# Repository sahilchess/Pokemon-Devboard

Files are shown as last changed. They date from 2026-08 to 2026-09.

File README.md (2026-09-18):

# [Pokemon Devboard](https://kicanvas.org/?repo=https%3A%2F%2Fgithub.com%2Fsahilchess%2FPokemon-Devboard%2Ftree%2Fmain%2FPCB_DESIGN)
 
a pokemon themed rp2040 dev board designed in kicad, arduino lookalike

[woah whats this?](https://forge.hackclub.com/projects/1680)



## features
 
- rp2040 mcu, 30 gpio broken out
- usb_c input with mcp1700 3.3v regulator
- w25q128jvs 16mb qspi flash for program storage
- 12mhz crystal oscillator
- reset button and bootsel button
- 2 user leds on gpio2 and gpio3
- 2 user buttons on gpio4 and gpio5
- swd debug header (swclk, swdio, gnd)
- gpioa and gpiob headers for full pin access
- power headers for gnd, 3v3, and 5v lines
- test pads for gnd, 3v3, 5v, swclk, swdio, run, and 2 mounting holes
- clear pinouts with silkscreen

## why i made this

i've always liked the arduino form factor. it's simple and just works. everyone knows it. but here's what got me thinkin, arduino is literally the biggest mcu maker in the world and they never made the chip better. they just stuck with the old 8-bit avrs while everything else moved on to faster processors.

so i wondered, what if i could take the rp2040, which is actually good, and put it in that arduino shape? no one was doing it. so i did it.

making this taught me a ton about power delivery, flash wiring, schematic design, all the stuff that goes into actually making something people can use. and honestly, it's just cool to know i bridged that gap. the arduino form factor is iconic because it works, and the rp2040 is fast and has tons of gpio. now you get both.

if you build with this, you get the form factor you already know how to use but way more power under the hood.

## power
 
usb_c feeds vbus into the mcp1700 330xxtt regulator, output is 3.3v and 5v. decoupling caps sit across usb_vdd, adc_avdd, vreg_vin, vreg_vout, and dvdd per the rp2040 datasheet recommendations.
 
## flash
 
w25q128jvs wired to the rp2040 qspi bus (qspi_ss, qspi_sclk, qspi_sd0 to sd3). sw1 is the bootsel button, pulls qspi_ss to select flash bootrom mode on boot.
 
## files
 
- pcb_design, kicad project, schematic and board layout
- production, gerbers and fab outputs ready to send out
- gerber.zip, zipped gerbers for ordering
- readme.md, this file

## getting started

just plug it in.

plug usb_c into your computer. it should show up as a usb device. download the rp2040 sdk or use the arduino ide with the rp2040 board package installed.

if you want to load firmware, hit the bootsel button (sw1) while plugging in usb or while pressing reset. this puts the board into bootloader mode and a new drive shows up on your computer. drag your .uf2 file onto it and you're done.

if you want to use the swd header for debugging, you need a debugger (picoprobe, j-link, whatever you have). the header is swclk, swdio, and gnd. connect them and you can step through code with gdb.

the two leds on gpio2 and gpio3 blink by default on boot so you know it's working. the two buttons on gpio4 and gpio5 are yours to do whatever with.

all 30 gpio pins are on the gpioa and gpiob headers so you can break out whatever you need. power headers have gnd, 3v3, and 5v if you're powering other stuff.

firmware: simple blink.ino [here](https://github.com/sahilchess/Pokemon-Devboard/blob/main/production/blink.ino)

## status
 
ready to buy from jlcpcb,prolly wont tho and will just redeem coins from shop.

## pictures






## Bill of Materials
[here](https://github.com/sahilchess/Pokemon-Devboard/blob/main/production/bom.csv)
<!--
| Component | Value | Qty | Footprint | LCSC Part # | Link | Unit Cost | Total |
|---|---|-----|---|---|---|---|---|
| C1-C8, C11, C12, C17 | 0.1µF | 11 | 0402 | C1525 | [LCSC](https://www.lcsc.com/product-detail/C1525.html?s_z=n_q_C1525&globalKeyword=C1525) | $0.0055 | $0.0605 |
| C9, C10 | 1µF | 2 | 0402 | C52923 | [LCSC](https://www.lcsc.com/product-detail/C52923.html?s_z=n_q_C52923&globalKeyword=C52923) | $0.0126 | $0.0252 |
| C13, C14 | 10µF | 2 | 0603 | C19702 | [LCSC](https://www.lcsc.com/product-detail/C19702.html?s_z=n_q_C19702&globalKeyword=C19702) | $0.0391 | $0.0782 |
| C15, C16 | 33pF | 2 | 0402 | C1562 | [LCSC](https://www.lcsc.com/product-detail/C1562.html?s_z=n_q_C1562&globalKeyword=C1562) | $0.0072 | $0.0144 |
| GPIO2, GPIO3 | LED | 2 | 0805 | C2297 | [LCSC](https://www.lcsc.com/product-detail/C2297.html?s_z=n_q_C2297&globalKeyword=C2297) | $0.0163 | $0.0326 |
| GPIO4, GPIO5, RUN1, SW1 | SW_Push | 4 | Alps SKRK | C720477 | [LCSC](https://www.lcsc.com/product-detail/C720477.html?s_z=n_q_C720477&globalKeyword=C720477) | $0.0531 | $0.2124 |
| J1 | USB-C Receptacle | 1 | HRO TYPE-C-31-M-12 | C165948 | [LCSC](https://www.lcsc.com/product-detail/C165948.html?s_z=n_q_C165948&globalKeyword=C165948) | $0.1716 | $0.1716 |
| J2 | GPIO Bank B | 1 | 1x11 Pin Socket | C124407 | [LCSC](https://www.lcsc.com/product-detail/C124407.html?s_z=n_q_C124407&globalKeyword=C124407) | $0.2734 | $0.2734 |
| J4 | GPIO Bank A | 1 | 1x18 Pin Socket | C124410 | [LCSC](https://www.lcsc.com/product-detail/C124410.html?s_z=n_q_C124410&globalKeyword=C124410) | $0.367 | $0.367 |
| J5 | Debug | 1 | 1x3 Pin Socket | C49257 | [LCSC](https://www.lcsc.com/product-detail/C49257.html?s_z=n_q_C49257&globalKeyword=C49257) | $0.0272 | $0.0272 |
| J6 | Power | 1 | 1x5 Pin Socket | C124414 | [LCSC](https://www.lcsc.com/product-detail/C124414.html?s_z=n_q_C124414&globalKeyword=C124414) | $0.1323 | $0.1323 |
| J8 | GND Line | 1 | 1x10 Pin Socket | C124407 | [LCSC](https://www.lcsc.com/product-detail/C124407.html?s_z=n_q_C124407&globalKeyword=C124407) | $0.2734 | $0.2734 |
| J9 | 3V3 Line | 1 | 1x10 Pin Socket | C124407 | [LCSC](https://www.lcsc.com/product-detail/C124407.html?s_z=n_q_C124407&globalKeyword=C124407) | $0.2734 | $0.2734 |
| J11 | 5V Line | 1 | 1x10 Pin Socket | C124407 | [LCSC](https://www.lcsc.com/product-detail/C124407.html?s_z=n_q_C124407&globalKeyword=C124407) | $0.2734 | $0.2734 |
| R1, R2 | 5.1K | 2 | 0402 | C25905 | [LCSC](https://www.lcsc.com/product-detail/C25905.html?s_z=n_q_C25905&globalKeyword=C25905) | $0.0043 | $0.0086 |
| R9, R10 | 220Ω | 2 | 0402 | C25091 | [LCSC](https://www.lcsc.com/product-detail/C25091.html?s_z=n_q_C25091&globalKeyword=C25091) | $0.0062 | $0.0124 |
| R3, R4 | 22Ω | 2 | 0402 | C25092 | [LCSC](https://www.lcsc.com/product-detail/C25092.html?s_z=n_q_C25092&globalKeyword=C25092) | $0.007 | $0.014 |
| R5, R7 | 1K | 2 | 0402 | C11702 | [LCSC](https://www.lcsc.com/product-detail/C11702.html?s_z=n_q_C11702&globalKeyword=C11702) | $0.0067 | $0.0134 |
| R6, R8, R11 | 10K | 3 | 0805 | C17414 | [LCSC](https://www.lcsc.com/product-detail/C17414.html?s_z=n_q_C17414&globalKeyword=C17414) | $0.0056 | $0.0168 |
| U1 | RP2040 | 1 | QFN-56 | C2040 | [LCSC](https://www.lcsc.com/product-detail/C2040.html?s_z=n_q_C2040&globalKeyword=C2040) | $0.993 | $0.993 |
| U2 | MCP1700x-330 | 1 | SOT-23 | C5446 | [LCSC](https://www.lcsc.com/product-detail/C5446.html?s_z=n_q_C5446&globalKeyword=C5446) | $0.1362 | $0.1362 |
| U3 | W25Q128JVS | 1 | SOIC-8 | C97521 | [LCSC](https://www.lcsc.com/product-detail/C97521.html?s_z=n_q_C97521&globalKeyword=C97521) | $2.5773 | $2.5773 |
| Y2 | 12MHz Crystal | 1 | 3225 4-Pin | C9002 | [LCSC](https://www.lcsc.com/product-detail/C9002.html?s_z=n_q_C9002&globalKeyword=C9002) | $0.0953 | $0.0953 |

**Total Components:** 72  
**Estimated Build Cost:** $48.28 USD

-->

**made for forge**

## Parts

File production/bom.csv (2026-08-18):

Component | Value | Quantity | Footprint | LCSC Part # | Link | Unit Cost (USD) | Total Cost (USD)
C1-C8, C11, C12, C17 | 0.1µF | 11 | 0402 | C1525 | https://www.lcsc.com/product-detail/C1525.html?s_z=n_q_C1525&globalKeyword=C1525 | 0.0055 | 0.0605
C9, C10 | 1µF | 2 | 0402 | C52923 | https://www.lcsc.com/product-detail/C52923.html?s_z=n_q_C52923&globalKeyword=C52923 | 0.0126 | 0.0252
C13, C14 | 10µF | 2 | 0603 | C19702 | https://www.lcsc.com/product-detail/C19702.html?s_z=n_q_C19702&globalKeyword=C19702 | 0.0391 | 0.0782
C15, C16 | 33pF | 2 | 0402 | C1562 | https://www.lcsc.com/product-detail/C1562.html?s_z=n_q_C1562&globalKeyword=C1562 | 0.0072 | 0.0144
GPIO2, GPIO3 | LED | 2 | 0805 | C2297 | https://www.lcsc.com/product-detail/C2297.html?s_z=n_q_C2297&globalKeyword=C2297 | 0.0163 | 0.0326
GPIO4, GPIO5, RUN1, SW1 | SW_Push | 4 | Alps SKRK | C720477 | https://www.lcsc.com/product-detail/C720477.html?s_z=n_q_C720477&globalKeyword=C720477 | 0.0531 | 0.2124
J1 | USB-C Receptacle | 1 | HRO TYPE-C-31-M-12 | C165948 | https://www.lcsc.com/product-detail/C165948.html?s_z=n_q_C165948&globalKeyword=C165948 | 0.1716 | 0.1716
J2 | GPIO Bank B | 1 | 1x11 Pin Socket | C124407 | https://www.lcsc.com/product-detail/C124407.html?s_z=n_q_C124407&globalKeyword=C124407 | 0.2734 | 0.2734
J4 | GPIO Bank A | 1 | 1x18 Pin Socket | C124410 | https://www.lcsc.com/product-detail/C124410.html?s_z=n_q_C124410&globalKeyword=C124410 | 0.367 | 0.367
J5 | Debug | 1 | 1x3 Pin Socket | C49257 | https://www.lcsc.com/product-detail/C49257.html?s_z=n_q_C49257&globalKeyword=C49257 | 0.0272 | 0.0272
J6 | Power | 1 | 1x5 Pin Socket | C124414 | https://www.lcsc.com/product-detail/C124414.html?s_z=n_q_C124414&globalKeyword=C124414 | 0.1323 | 0.1323
J8 | GND Line | 1 | 1x10 Pin Socket | C124407 | https://www.lcsc.com/product-detail/C124407.html?s_z=n_q_C124407&globalKeyword=C124407 | 0.2734 | 0.2734
J9 | 3V3 Line | 1 | 1x10 Pin Socket | C124407 | https://www.lcsc.com/product-detail/C124407.html?s_z=n_q_C124407&globalKeyword=C124407 | 0.2734 | 0.2734
J11 | 5V Line | 1 | 1x10 Pin Socket | C124407 | https://www.lcsc.com/product-detail/C124407.html?s_z=n_q_C124407&globalKeyword=C124407 | 0.2734 | 0.2734
R1, R2 | 5.1K | 2 | 0402 | C25905 | https://www.lcsc.com/product-detail/C25905.html?s_z=n_q_C25905&globalKeyword=C25905 | 0.0043 | 0.0086
R9, R10 | 220Ω | 2 | 0402 | C25091 | https://www.lcsc.com/product-detail/C25091.html?s_z=n_q_C25091&globalKeyword=C25091 | 0.0062 | 0.0124
R3, R4 | 22Ω | 2 | 0402 | C25092 | https://www.lcsc.com/product-detail/C25092.html?s_z=n_q_C25092&globalKeyword=C25092 | 0.007 | 0.014
R5, R7 | 1K | 2 | 0402 | C11702 | https://www.lcsc.com/product-detail/C11702.html?s_z=n_q_C11702&globalKeyword=C11702 | 0.0067 | 0.0134
R6, R8, R11 | 10K | 3 | 0805 | C17414 | https://www.lcsc.com/product-detail/C17414.html?s_z=n_q_C17414&globalKeyword=C17414 | 0.0056 | 0.0168
U1 | RP2040 | 1 | QFN-56 | C2040 | https://www.lcsc.com/product-detail/C2040.html?s_z=n_q_C2040&globalKeyword=C2040 | 0.993 | 0.993
U2 | MCP1700x-330 | 1 | SOT-23 | C5446 | https://www.lcsc.com/product-detail/C5446.html?s_z=n_q_C5446&globalKeyword=C5446 | 0.1362 | 0.1362
U3 | W25Q128JVS | 1 | SOIC-8 | C97521 | https://www.lcsc.com/product-detail/C97521.html?s_z=n_q_C97521&globalKeyword=C97521 | 2.5773 | 2.5773
Y2 | 12MHz Crystal | 1 | 3225 4-Pin | C9002 | https://www.lcsc.com/product-detail/C9002.html?s_z=n_q_C9002&globalKeyword=C9002 | 0.0953 | 0.0953

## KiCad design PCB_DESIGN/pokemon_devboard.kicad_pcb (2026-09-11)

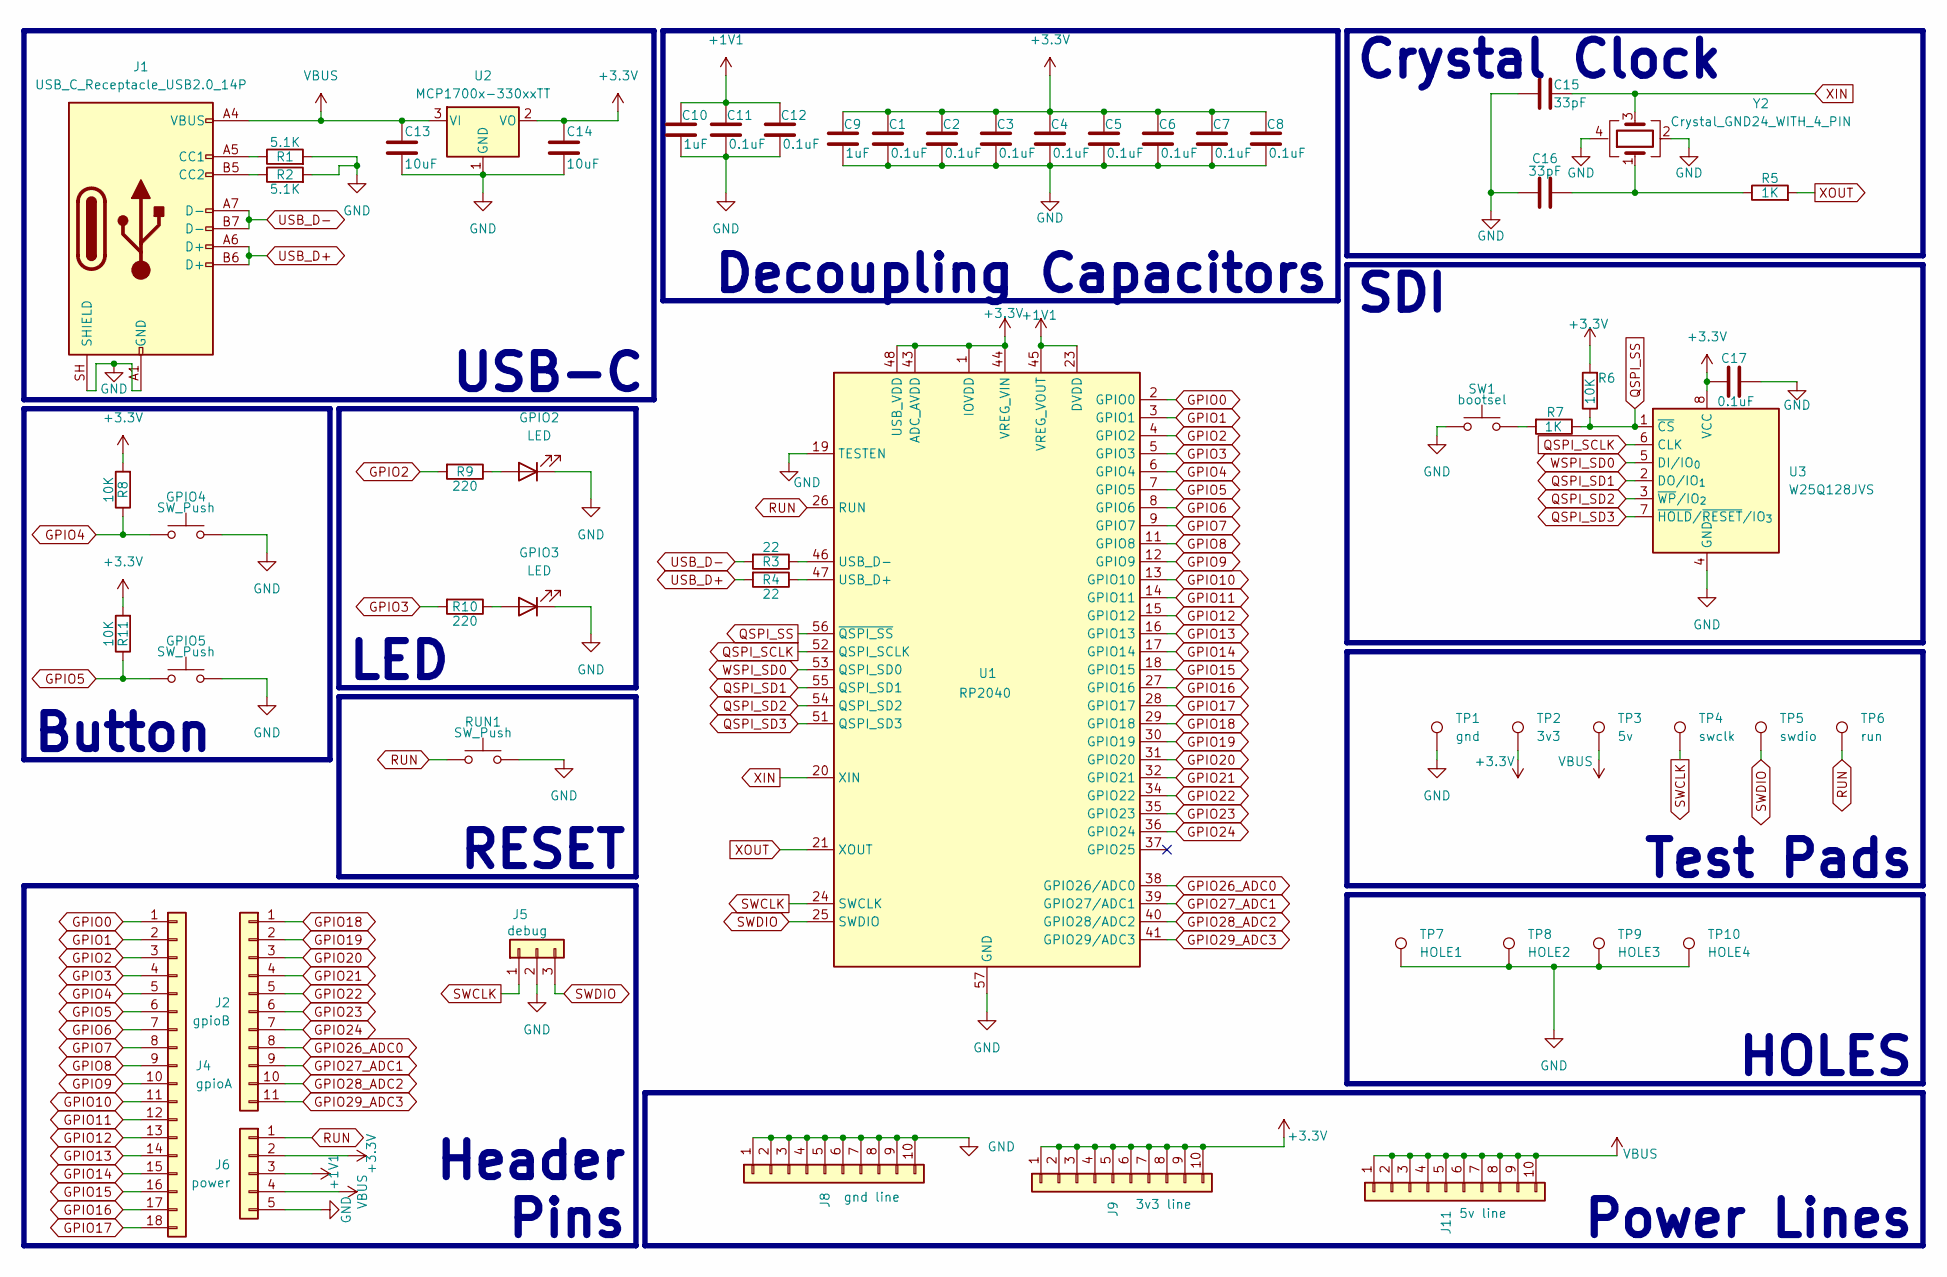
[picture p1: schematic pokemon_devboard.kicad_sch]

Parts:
C1, C2, C3, C4, C5, C6, C7, C8, C11, C12, C17: 0.1uF; C_0402_1005Metric
C9, C10: 1uF; C_0402_1005Metric
C13, C14: 10uF; C_0603_1608Metric
C15, C16: 33pF; C_0402_1005Metric
GPIO2, GPIO3: LED; LED_0805_2012Metric
GPIO4, GPIO5: SW_Push; SW_Push_SPST_NO_Alps_SKRK
J1: USB_C_Receptacle_USB2.0_14P; USB_C_Receptacle_HRO_TYPE-C-31-M-12
J2: gpioB; PinSocket_1x11_P2.54mm_Vertical
J4: gpioA; PinSocket_1x18_P2.54mm_Vertical
J5: debug; PinSocket_1x03_P2.54mm_Vertical
J6: power; PinSocket_1x05_P2.54mm_Vertical
J8: gnd line; PinSocket_1x10_P2.54mm_Vertical
J9: 3v3 line; PinSocket_1x10_P2.54mm_Vertical
J11: 5v line; PinSocket_1x10_P2.54mm_Vertical
R1, R2: 5.1K; R_0402_1005Metric
R3, R4: 22; R_0402_1005Metric
R5, R7: 1K; R_0402_1005Metric
R6, R8, R11: 10K; R_0805_2012Metric
R9, R10: 220; R_0402_1005Metric
RUN1: SW_Push; SW_Push_SPST_NO_Alps_SKRK
SW1: bootsel; SW_Push_SPST_NO_Alps_SKRK
TP1: gnd; TestPoint_Pad_D1.5mm
TP2: 3v3; TestPoint_Pad_D1.5mm
TP3: 5v; TestPoint_Pad_D1.5mm
TP4: swclk; TestPoint_Pad_D1.5mm
TP5: swdio; TestPoint_Pad_D1.5mm
TP6: run; TestPoint_Pad_D1.5mm
TP7: HOLE1; MountingHole_2.2mm_M2_Pad
TP8: HOLE2; MountingHole_2.2mm_M2_Pad
TP9: HOLE3; MountingHole_2.2mm_M2_Pad
TP10: HOLE4; MountingHole_2.2mm_M2_Pad
U1: RP2040; QFN-56-1EP_7x7mm_P0.4mm_EP3.2x3.2mm
U2: MCP1700x-330xxTT; SOT-23
U3: W25Q128JVS; SOIC-8_5.3x5.3mm_P1.27mm
Y2: Crystal_GND24_WITH_4_PIN; Crystal_SMD_3225-4Pin_3.2x2.5mm

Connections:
+1V1: C10.1, C11.1, C12.1, J6.3, U1.23 (DVDD), U1.45 (VREG_VOUT), U1.50 (DVDD)
+3.3V: C1.1, C2.1, C3.1, C4.1, C5.1, C6.1, C7.1, C8.1, C9.1, C14.1, C17.1, J6.2, J9.1, J9.2, J9.3, J9.4, J9.5, J9.6, J9.7, J9.8, J9.9, J9.10, R6.2, R8.2, R11.2, TP2.1 (1_1), U1.1 (IOVDD), U1.10 (IOVDD), U1.22 (IOVDD), U1.33 (IOVDD), U1.42 (IOVDD), U1.43 (ADC_AVDD), U1.44 (VREG_VIN), U1.48 (USB_VDD), U1.49 (IOVDD), U2.2 (VO), U3.8 (VCC)
GND: C1.2, C2.2, C3.2, C4.2, C5.2, C6.2, C7.2, C8.2, C9.2, C10.2, C11.2, C12.2, C13.2, C14.2, C15.1, C16.1, C17.2, GPIO2.1 (K), GPIO3.1 (K), GPIO4.2, GPIO5.2, J1.A1 (GND), J1.A12 (GND), J1.B1 (GND), J1.B12 (GND), J1.SH (SHIELD), J5.2, J6.5, J8.1, J8.2, J8.3, J8.4, J8.5, J8.6, J8.7, J8.8, J8.9, J8.10, R1.2, R2.2, RUN1.2, SW1.1, TP1.1 (1_1), TP7.1 (1_1), TP8.1 (1_1), TP9.1 (1_1), TP10.1 (1_1), U1.19 (TESTEN), U1.57 (GND), U2.1 (GND), U3.4 (GND), Y2.2 (G), Y2.4
GPIO0: J4.1, U1.2 (GPIO0)
GPIO1: J4.2, U1.3 (GPIO1)
GPIO2: J4.3, R9.2, U1.4 (GPIO2)
GPIO3: J4.4, R10.2, U1.5 (GPIO3)
GPIO4: GPIO4.1, J4.5, R8.1, U1.6 (GPIO4)
GPIO5: GPIO5.1, J4.6, R11.1, U1.7 (GPIO5)
GPIO6: J4.7, U1.8 (GPIO6)
GPIO7: J4.8, U1.9 (GPIO7)
GPIO8: J4.9, U1.11 (GPIO8)
GPIO9: J4.10, U1.12 (GPIO9)
GPIO10: J4.11, U1.13 (GPIO10)
GPIO11: J4.12, U1.14 (GPIO11)
GPIO12: J4.13, U1.15 (GPIO12)
GPIO13: J4.14, U1.16 (GPIO13)
GPIO14: J4.15, U1.17 (GPIO14)
GPIO15: J4.16, U1.18 (GPIO15)
GPIO16: J4.17, U1.27 (GPIO16)
GPIO17: J4.18, U1.28 (GPIO17)
GPIO18: J2.1, U1.29 (GPIO18)
GPIO19: J2.2, U1.30 (GPIO19)
GPIO20: J2.3, U1.31 (GPIO20)
GPIO21: J2.4, U1.32 (GPIO21)
GPIO22: J2.5, U1.34 (GPIO22)
GPIO23: J2.6, U1.35 (GPIO23)
GPIO24: J2.7, U1.36 (GPIO24)
GPIO26_ADC0: J2.8, U1.38 (GPIO26/ADC0)
GPIO27_ADC1: J2.9, U1.39 (GPIO27/ADC1)
GPIO28_ADC2: J2.10, U1.40 (GPIO28/ADC2)
GPIO29_ADC3: J2.11, U1.41 (GPIO29/ADC3)
unnamed: C16.2, R5.1, Y2.1
unnamed: GPIO2.2 (A), R9.1
unnamed: GPIO3.2 (A), R10.1
unnamed: J1.A5 (CC1), R1.1
unnamed: J1.B5 (CC2), R2.1
unnamed: R7.2, SW1.2
unnamed: R4.1, U1.47 (USB_D+)
unnamed: R3.1, U1.46 (USB_D-)
QSPI_SCLK: U1.52 (QSPI_SCLK), U3.6 (CLK)
QSPI_SD1: U1.55 (QSPI_SD1), U3.2 (DO/IO_{1})
QSPI_SD2: U1.54 (QSPI_SD2), U3.3 (~WP/IO_{2})
QSPI_SD3: U1.51 (QSPI_SD3), U3.7 (~HOLD/~RESET/IO_{3})
QSPI_SS: R6.1, R7.1, U1.56 (~QSPI_SS), U3.1 (~CS)
RUN: J6.1, RUN1.1, TP6.1 (1_1), U1.26 (RUN)
SWCLK: J5.1, TP4.1 (1_1), U1.24 (SWCLK)
SWDIO: J5.3, TP5.1 (1_1), U1.25 (SWDIO)
USB_D+: J1.A6 (D+), J1.B6 (D+), R4.2
USB_D-: J1.A7 (D-), J1.B7 (D-), R3.2
VBUS: C13.1, J1.A4 (VBUS), J1.A9 (VBUS), J1.B4 (VBUS), J1.B9 (VBUS), J6.4, J11.1, J11.2, J11.3, J11.4, J11.5, J11.6, J11.7, J11.8, J11.9, J11.10, TP3.1 (1_1), U2.3 (VI)
WSPI_SD0: U1.53 (QSPI_SD0), U3.5 (DI/IO_{0})
XIN: C15.2, U1.20 (XIN), Y2.3
XOUT: R5.2, U1.21 (XOUT)

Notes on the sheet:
SDI
USB-C
Decoupling Capacitors
HOLES
Test Pads
LED
Button
Power Lines
RESET
Crystal Clock
Header Pins

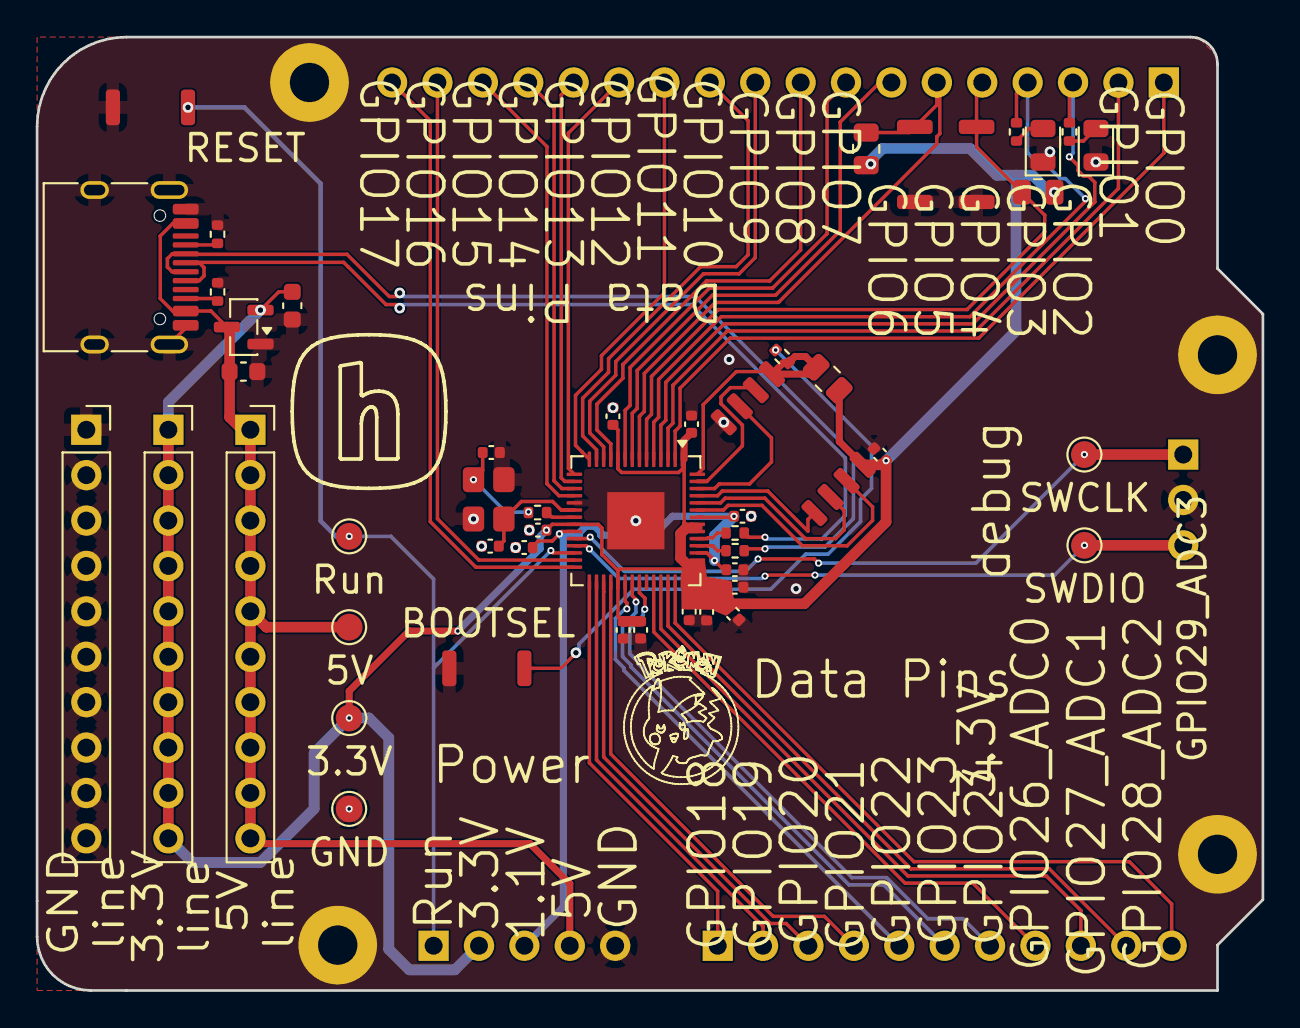
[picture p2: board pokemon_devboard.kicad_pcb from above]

Board: 2 copper layers, 68.6 x 53.3 mm, 56 parts (0 on the bottom side), 54 nets.

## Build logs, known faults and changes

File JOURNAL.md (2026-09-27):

---
title: "Pokemon Devboard"
author: "sahil"
description: "RP2040 development board inspired by Arduino shape with Pokémon theming"
created_at: "2026-05-25"
---

# May 25: the idea

For the idea, I wanted to create a custom devboard because I thought that was cool. I didn't know how to so I will follow a guide on Macondo. Imma choose a Pokémon theme because i love Pokémon (obviously).  



**Total time spent: 0 hours**

# May 25: Started the schematic

after a meeting with a macondo guide, i read the room and saw that most of it was: see raspberry pi pico, find that part datasheet, put it in schematic. so imma leave the guide and do it myself... here is the RP2040 with the decoupling caps. these are needed to stabilize voltage and reduce high-frequency noise



hackatime: [14m](https://lapse.hackclub.com/timelapse/PWaohIea3p6Q) -- [1hr 20m](https://lapse.hackclub.com/timelapse/IpuH7RUJf16H)

**Total time spent: 1.6 hours**

# May 25: working on schematic

firstly, the usb is needed to get power to the stuff. next, we have the buttons and leds that are meta with custom devboards. and lastly, we have our crystal and SDI for flash memory and the crystal for a clock. I had to go to the websites to find the datasheets. i was easily able to find these after searching up the par





i realized I also need header pins so here they are. Additionally, I added those cool blue boxes for labeling the parts and stuff. here is the finished design





hackatime: [1hr 12m](https://lapse.hackclub.com/timelapse/twbUsFzCFTM-) 
i will put 1 hr cuz i lolled around a bit.

**Total time spent: 1.2 hours**

# May 26: placed parts!

now that i finished assigning parts, i also finished placing all my parts on the board. this was simple bc i js looked at a pico i have at my desk and put stuff so it looks like a normal pico. 



hackatime: [1hr 21m](https://lapse.hackclub.com/timelapse/brgqWpoutHl4)

**Total time spent: 1.4 hours**

# May 26: Wiring is painful

tried an autorouter called freerouting to save time but it made a mess, traces crossing weird and not respecting spacing, so i scrapped that and did it all by hand instead. the hard part isn't drawing the traces, it's keeping enough space for everything, keeping a consistent style across the board, and not wasting space i'll want later for the copper pour



As I said, finished routing by hand after freerouting failed. No ratlines left which means every net is connected. next up is fixing drc errors and adding the silkscreen art, still not sure if that or the hand soldering later will be the bigger pain

to reiterate, ive been thinking about whether i even want to hand solder this myself, my desk isn't protected with a silicone mat right now so if i get funding for the board i'll probably grab soldering gear and a mat before touching an iron to it

that was very hard. i dont know how the makers of the raspberry pi pico did it. i think that a bigger board will make this hella easy

no ratlines and done routing




hackatime: [39m](https://lapse.hackclub.com/timelapse/BkfRdCr-NQaL) [1hr 6m](https://lapse.hackclub.com/timelapse/W5jPpFdagNB1) [3hr 54m](https://lapse.hackclub.com/timelapse/Kw_7oLqvejIB) [33m](https://lapse.hackclub.com/timelapse/6qH-JN70Ru1n)

**Total time spent: 6.2 hours**

# May 27: Done!!!!! (*read note)

made a pikachu banner in canva, happy with how it came out. finished the drc cleanup and silkscreen after that, uploaded everything to github, and pulled a quote from jlcpcb so i know roughly what this is going to cost




swapped the w25q128jveiq flash chip to a bigger footprint because the smaller package wasn't in stock on jlcpcb, and an out of stock part would've held up the whole order. the bom ballooned because of that so i'm going through it to trim cost back down. i had to reformat my bom becuase the one on kicad sucks bc jlcpcb doesnt requires a different format.



hackatime: [2hr 16m](https://lapse.hackclub.com/timelapse/jjtq7Aw4q0OY) [1hr 1m](https://lapse.hackclub.com/timelapse/ulGjAfmP5DVY) [1hr 7m](https://lapse.hackclub.com/timelapse/k3W54B_Pve_G) [1hr 16m](https://lapse.hackclub.com/timelapse/rbFRxTP0l39V) [47m](https://lapse.hackclub.com/timelapse/rbFRxTP0l39V) 

note from the future: if i was able to cut that lapse, i would. i really dont like how unorganized it was and i didnt do 100% designing. also, this was my first ship that i realized was boring (*read next entry). and OMG in these lapse streams i was so distracted :heavysob: 

**Total time spent: 6.5 hours**

# Jul 10: deciding to redesign

while i did say i was close to submitting for funding, that was the bad design that i dont like. i am redesigning rn. okay after a long side quest i am back to this devboard. i was thinking that picos are just too basic and the board i have rn is really similar to a normal rpp. imma make a arduino.



hackatime: n/a

**Total time spent: 0.2 hours**

# Jul 11: goal

arduinos are the most beginner friendly boards out there but the mcu itself is pretty weak compared to something like the rp2040 on a pico. so the idea here is to get the best of both, pico level performance with the arduino form factor people already know

started by taking a pico and adding female header pins plus gnd and 3v3 rails, similar to how arduino prototype shields are laid out. next revision i want to organize the pinout more clearly, gpios grouped together, grounds grouped together, so it reads more like a real arduino shield than a breakout board

i may also add some extra stuff... stay tuned to find out!



hackatime: [1hr 9m](https://lapse.hackclub.com/timelapse/UZxMyfLuvEW2) [2hr 47m](https://lapse.hackclub.com/timelapse/0YN2RIAIrCG2)

**Total time spent: 3.9 hours**

# Jul 14: 2 designs

landed on two directions, one that looks like a pico breakout and one that looks like an arduino. tried to keep traces neat on both, but i'm leaning toward the arduino looking one since that was the whole point of this board, familiarity for people who already know arduino pinouts. i found the arduino template board on github and i kinda like it but the corners are pretty sharp.

both still need small cleanup like silkscreen before either is final




hackatime: [58m](https://lapse.hackclub.com/timelapse/zcPcXlxSsXgz) [1hr 26m](https://lapse.hackclub.com/timelapse/VHkb8mKCkyZk) [4m](https://lapse.hackclub.com/timelapse/mxhQwuakfWb2) [1hr 43m](https://lapse.hackclub.com/timelapse/mxhQwuakfWb2) [1hr 43m](https://lapse.hackclub.com/timelapse/KtD70gZxfL1F)
**Total time spent: 5.9 hours**

# Jul 14: adding stuff and making it cleaner

picked the arduino style design and cleaned it up further. main thing left is fabrication and production, though i might still add a couple more features if i think of something worth the extra bom cost

got production numbers together. found that setting jlcpcb to only assemble 2 of the 5 boards instead of all 5 saves about $20, since i don't need every panel populated right now and can hand solder the rest later if i want more.

for the changes i added: i rounded the corners on the arduino so it looks better, i added test pads on the left, i added power rails on the left, and i added hella tuff silkscreen.





hackatime: [26m](https://lapse.hackclub.com/timelapse/m449X6b-E8Zw) [4hr 52m](https://lapse.hackclub.com/timelapse/NlCVlNKGtRlv) [2hrs](https://lapse.hackclub.com/timelapse/QFIhM1hQPQil)

**Total time spent: 7.3 hours**

# Aug 17: made it ready for more production

did my bom (this may not be in the hackatime lapses idk im not really sure). this costs alot more than when i look int july so im just gonna buy stmg from the forge shop instead of buying the board. also the forge has its own special bom format so i have one in ignore/ for the bom i will upload for jlcpcb and one in procution/ that is the one for forge.



hackatime: [47m](https://lapse.hackclub.com/timelapse/Pao3cjAEDZEO) 

**Total time spent: 0.8 hours**

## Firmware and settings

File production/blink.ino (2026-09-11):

#define led1_pin 2
#define led2_pin 3

void setup() {
    pinMode(led1_pin, OUTPUT);
    pinMode(led2_pin, OUTPUT);
}

void loop() {
    digitalWrite(led1_pin, HIGH);
    digitalWrite(led2_pin, LOW);
    delay(500);
    digitalWrite(led1_pin, LOW);
    digitalWrite(led2_pin, HIGH);
    delay(500);
}

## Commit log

2026-06-02 Add README for The Pikachu devboard
    Add a new README describing The Pikachu — a custom RP2040-based devboard designed in KiCad. The document includes a project overview, hardware-at-a-glance (MCU: RP2040, USB-C, W25Q128 flash, MCP1700 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
2026-06-20 production updates
    [Pokemon Devboard.kicad_sch, bom.csv, designators.csv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]
2026-06-21 added a bigger W25Q128JVEIQ
    bc the smaller one wasnt availible in jlcpcb
    [Pokemon Devboard.csv, Pokemon Devboard.kicad_sch, bom.csv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]
2026-06-21 bom stuff
    [bom - Copy.csv, bom-from-jlcpcb.xlsx]
2026-06-21 Update bom - Copy.csv
    [bom - Copy.csv]
2026-06-21 Update and rename bom - Copy.csv to bom-main.csv
    [bom-main.csv]
2026-06-21 prod update
    [Pokemon Devboard.kicad_sch, bom.csv, positions.csv]
2026-07-15 arduino version 2
    [Pokemon Devboard.kicad_sch, bom-kicad.csv, bom-main.csv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]
2026-09-07 Revise JOURNAL.md with design updates and reflections
    Updated journal entries with detailed reflections on the design process, including changes to the schematic, PCB layout, and BOM adjustments. Added images and clarified time spent on various tasks.
2026-09-09 Update Bill of Materials note in README.md
2026-09-11 Add LED blinking functionality in blink.ino
2026-09-11 Add Bill of Materials link to README
    Added a link to the Bill of Materials in the README.
2026-09-11 add cad
    [pokemon_devboard.kicad_pcb]
